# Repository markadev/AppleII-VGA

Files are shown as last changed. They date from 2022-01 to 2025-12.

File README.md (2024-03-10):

# Apple II VGA Card

This project is a VGA card for Apple II computers to ouput a crisp RGB signal to a
VGA monitor instead of having to rely on the composite output. This is accomplished
by snooping the 6502 bus and creating a shadow copy of the video memory within a
Raspberry Pi Pico, then processing the raw video memory contents to output a "perfect"
signal.

    +------+                +-----+      +-----------+
    | 6502 |________________| RAM |______| Composite | 
    | CPU  |  System   \    +-----+      | Video Gen |
    +------+   Bus     |                 +-----------+
                       |    +-----------+
                       \____| Raspberry |_________________\
                            |  Pi Pico  |   640x480 VGA   /
                            +-----------+

These features are currently supported:
 * Generates a 640x480@60 VGA signal with 3 bits per color channel using resistor DACs
 * Text mode (monochrome)
 * Lo-res mode with no color fringing between the chunky pixels
 * Hi-res mode with simulated NTSC artifact color
 * Mixed lo-res and hi-res modes with monochrome text and no color fringing
 * Apple IIe video modes: 80-column text, double-lores, & double-hires
   (thanks to @dkgrizzly and @Paco1979)
 * Soft-monochrome mode to force display as if on a monochrome monitor
 * Some Video-7 RGB card extended graphical modes are implemented
 * Compatibility with Videx VideoTerm modes on Apple II+ (thanks to @abaffa)

I had these goals in mind during design:
 * Generate video out to a more modern display - I don't have any old CRTs for
   displaying composite signals any more and composite to HDMI adapters don't work well.
 * Generate crisp video - I wanted "perfect" video output, the way that it should have
   been barring technical difficulties of displays in 1980. So like, no NTSC artifact
   coloring where it's not supposed to be.
 * Non-invasive - I didn't want to have to solder or modify my logic board.
 * Common parts - The parts to build should be cheap and easy to get anywhere,
   just like the original Apple II
 * Open-source - If this helps anyone else make their Apple II better then that's
   a bonus.

I also wanted to see if a Pi Pico could actually work on an 8-bit CPU bus, since the docs
say it should work but there were no code examples.

## Project Status

This is currently a DIY project that several folks have built on their own, ranging from
[hand-wired prototype boards](docs/prototype_card.jpg) to
[custom](https://user-images.githubusercontent.com/7944844/243266290-d05ce815-0a3d-4464-a4da-49dd44d71e92.jpg)
[PCBs](https://user-images.githubusercontent.com/94628/253134471-0d5ad359-75ae-400a-acfa-885c80c36e78.jpg)
and run in their Apple II+'s and IIe's. I consider it to be pretty stable at this point.

Included in this repo are:
 * The main expansion board [KiCad Project](AppleVGA/), [Schematics](AppleVGA/AppleVGA.pdf),
   [BOM](AppleVGA/AppleVGA_BOM.csv), and [Gerber files](AppleVGA/outputs/)
 * An optional connector board [KiCad Project](AppleVGA-Connector/),
   [Schematics](AppleVGA-Connector/AppleVGA-Connector.pdf),
   [BOM](AppleVGA-Connector/AppleVGA-Connector_BOM.csv),
   and [Gerber files](AppleVGA-Connector/outputs/). (You could also build a custom cable instead)
 * The [source code for the Pi Pico microcontroller](pico/)

If you're going to build a card then check the [assembly guide](docs/Assembly.md) and
[hardware changelog](AppleVGA/CHANGELOG.txt) for important notes.

Many thanks go to the folks in the Discussion area to help push this project forward with bug
fixes & reports, and design ideas!

**Main board**
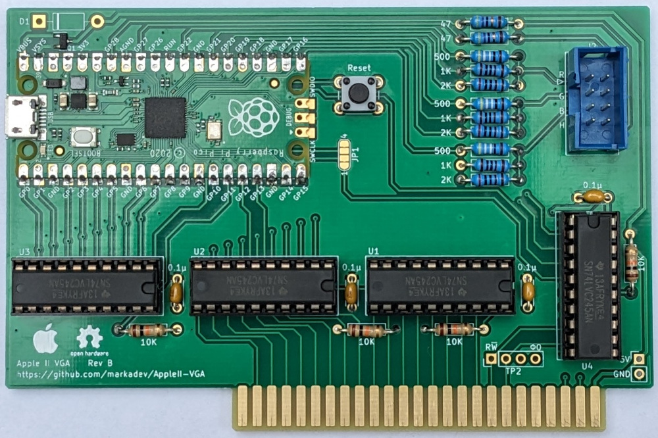
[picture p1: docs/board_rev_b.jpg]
Main board


**Connector board**
_thanks to @swetland for [this idea](https://github.com/markadev/AppleII-VGA/discussions/15#discussioncomment-6432841)_

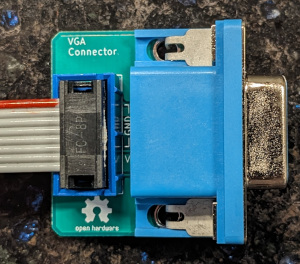
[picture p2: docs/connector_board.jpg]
Connector board


**In the wild**
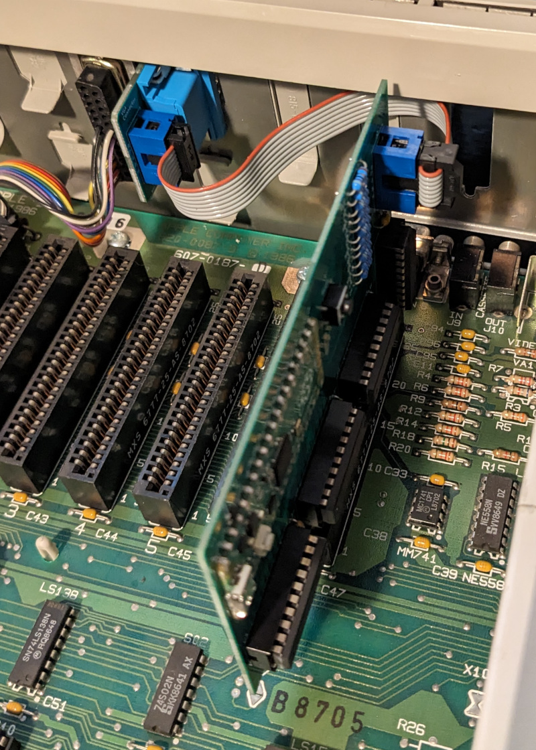
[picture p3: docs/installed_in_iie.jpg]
Live action shot


## Comparisons

Here are a few comparisons of the VGA card output vs composite video through
a cheap composite -> HDMI adapter

**Text**
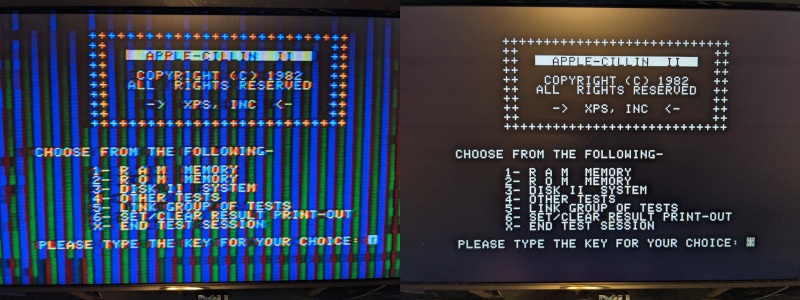
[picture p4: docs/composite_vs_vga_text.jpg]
Text Mode


**Lores**
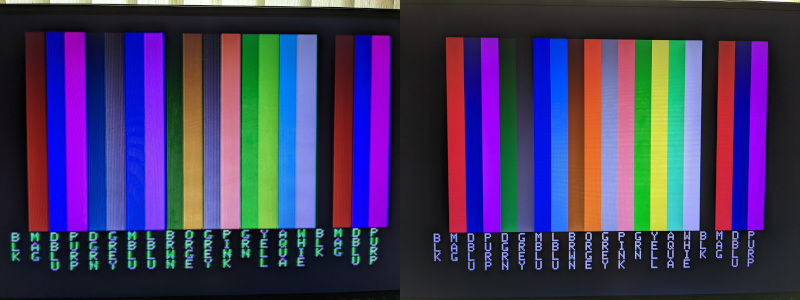
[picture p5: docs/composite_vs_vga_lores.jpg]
Lores Mode


**Hires**
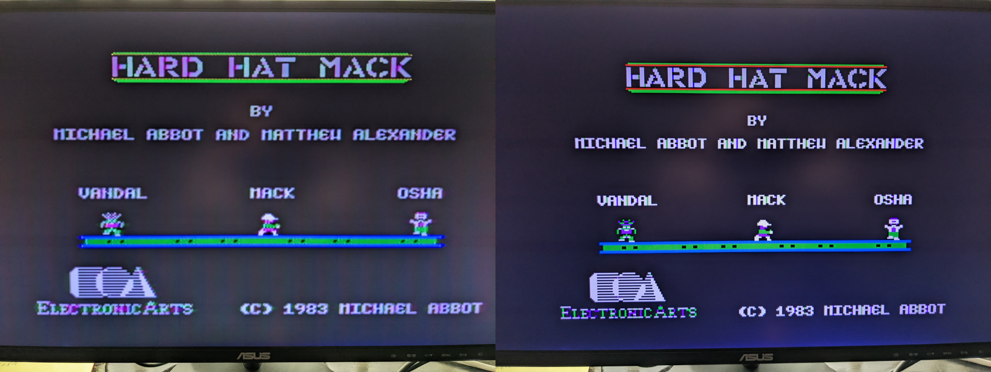
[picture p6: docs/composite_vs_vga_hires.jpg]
Hires Mode


**DHires**
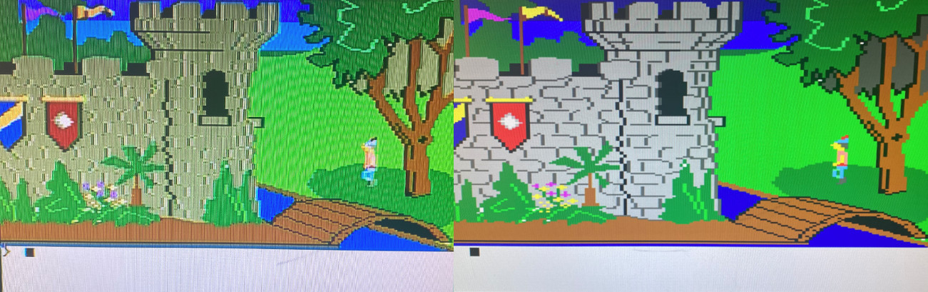
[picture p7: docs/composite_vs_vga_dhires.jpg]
DHires Mode


**80 Columns**
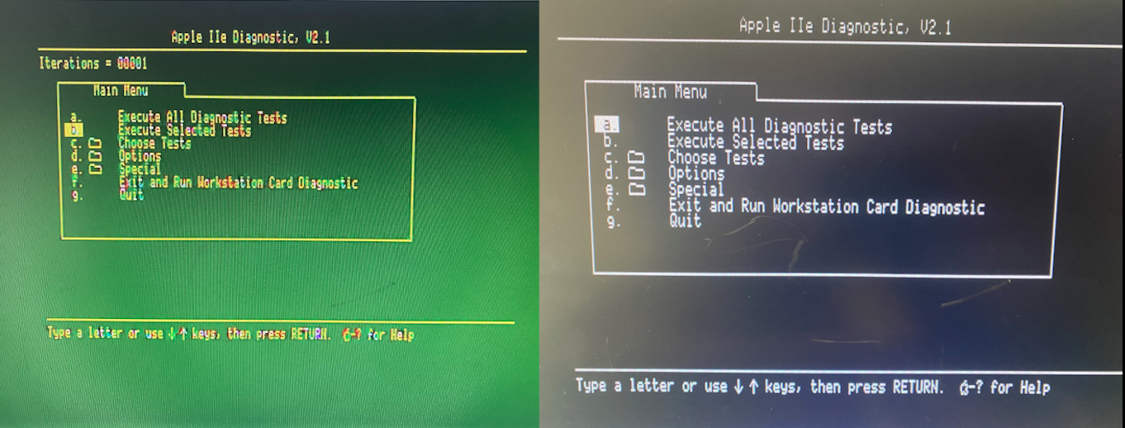
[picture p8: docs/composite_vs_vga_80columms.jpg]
80 Columns Mode


## 80 Column support for the Apple II+

The firmware implements Videx VideoTerm compatibility when there's a VideoTerm card installed
in slot 3. It's not enabled by default but if you have a Videx VideoTerm card in slot 3
then you can enable 80 column VGA support using the Configuration Disk image. The VGA card
can still be installed in any slot.

**Apple II+ running 80 Columns Examples**

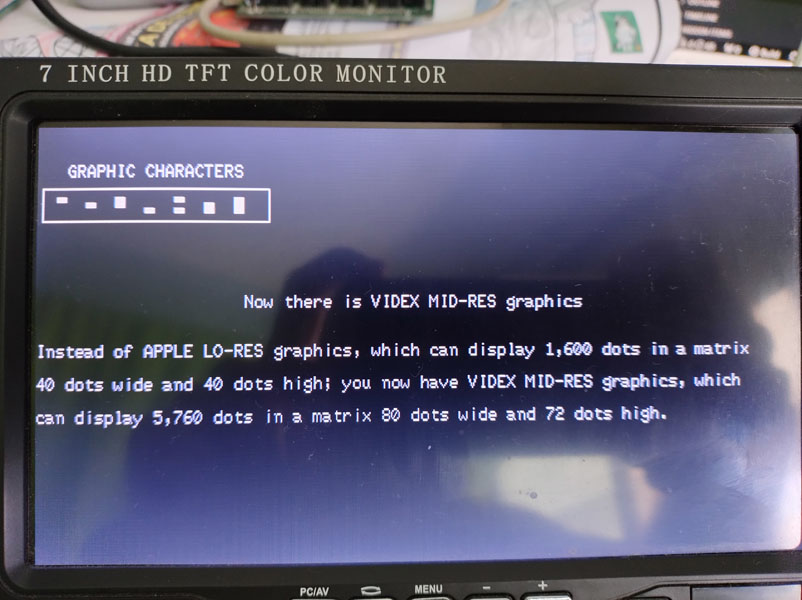
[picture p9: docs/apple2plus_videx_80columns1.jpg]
AppleII 80 Columms Mode 1

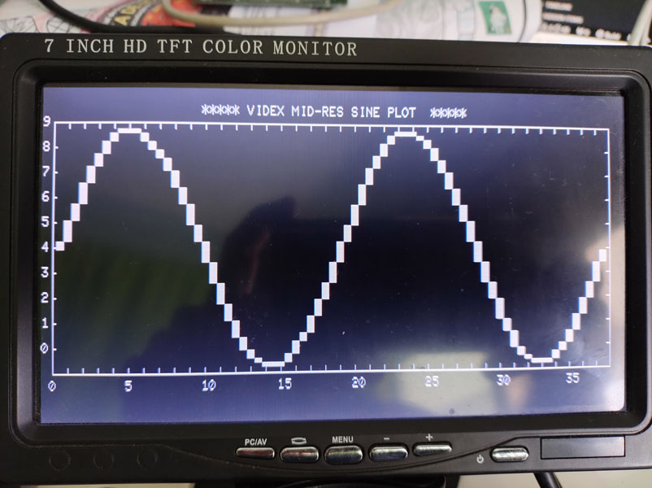
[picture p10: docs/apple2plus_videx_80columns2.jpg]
AppleII 80 Columms Mode 2

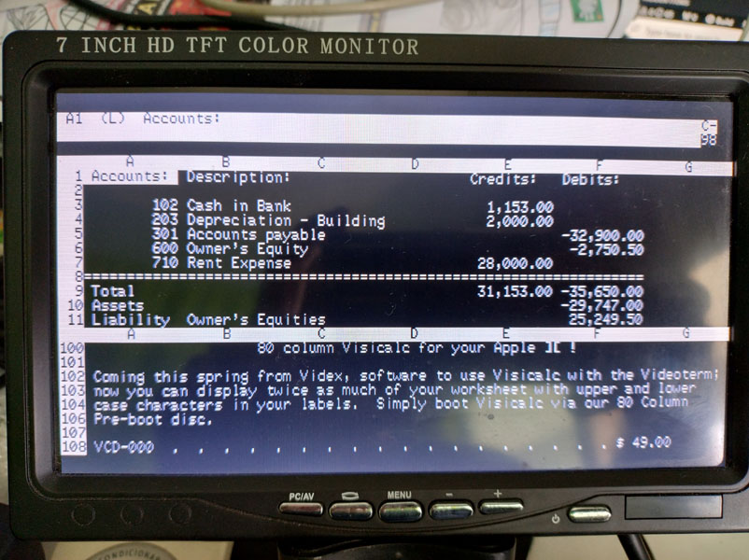
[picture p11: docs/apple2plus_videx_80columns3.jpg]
AppleII 80 Columms Mode 3


## Future work

With the Rev B hardware design, the firmware has access to the Apple bus' SYNC signal
when installed in slot 7. Theoretically the firmware could synchronize the VGA display
scans with the video hardware in the Apple II.

Though possible, it looks like it would be a large overhaul to implement this synchronization
and I've found no real-world use for it so I don't plan on completing this functionality.

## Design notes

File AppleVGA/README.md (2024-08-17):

# AppleII-VGA expansion card

Requirements:
  - KiCad 8.0 or later

This project uses additional KiCad libraries:
 - https://github.com/ncarandini/KiCad-RP-Pico

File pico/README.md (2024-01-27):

# Set Up Raspberry Pi Pico SDK and build the firmware

## Windows Subsystem for Linux (WSL)
Windows Subsystem for Linux (WSL) allows you to install a complete Ubuntu terminal environment in minutes on your Windows machine, allowing you to develop cross-platform applications without leaving Windows. [Install Ubuntu on WSL for Windows](https://ubuntu.com/tutorials/install-ubuntu-on-wsl2-on-windows-10#1-overview)

## Install development packages
```shell
sudo apt update
sudo apt install -y build-essential git cmake gcc-arm-none-eabi
```

## Download the Pico SDK
```shell
git clone https://github.com/raspberrypi/pico-sdk.git ~/pico-sdk
git -C ~/pico-sdk submodule update --init
export PICO_SDK_PATH=~/pico-sdk
```

## Build the firmware for Apple IIe
```shell
git clone https://github.com/markadev/AppleII-VGA.git ~/AppleII-VGA
cd ~/AppleII-VGA/pico
mkdir build
cd build
cmake -DAPPLE_MODEL=IIE -DCMAKE_BUILD_TYPE=Release ..
make
$ ls *uf2
...
applevga.uf2
```

## Build the firmware for Apple II+
```shell
git clone https://github.com/markadev/AppleII-VGA.git ~/AppleII-VGA
cd ~/AppleII-VGA/pico
mkdir build
cd build
cmake -DAPPLE_MODEL=IIPLUS -DCMAKE_BUILD_TYPE=Release ..
make
$ ls *uf2
...
applevga.uf2
```

## Install the firmware
Hold down the BOOTSEL button and connect the Raspberry Pi Pico to your PC via micro USB cable. Once Pico is
connected release the BOOTSEL button. Pi Pico should be connected to PC with USB mass storage device mode.

A disk volume called RPI-RP2 will appear on your computer. Drag and drop the applevga.uf2 file to that volume.
RPI-RP2 will unmount and Pico will start the program.

## Stand-alone test pattern image
There's a test pattern image in the source code that one can set to display immediately at power on, and Pico
microcontroller can be powered entirely from USB. To enable test pattern just uncomment `RENDER_TEST_PATTERN`
flag in `render.h`:
```
// #define RENDER_TEST_PATTERN
```
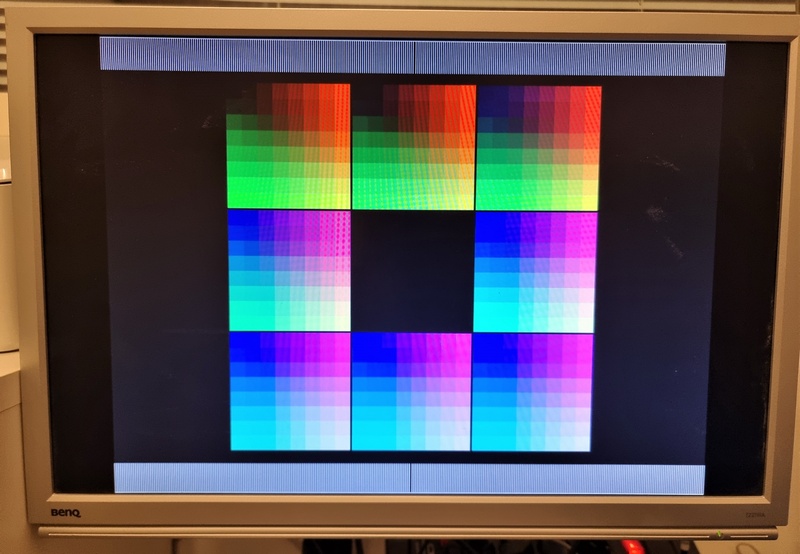
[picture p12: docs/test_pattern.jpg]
Test Pattern


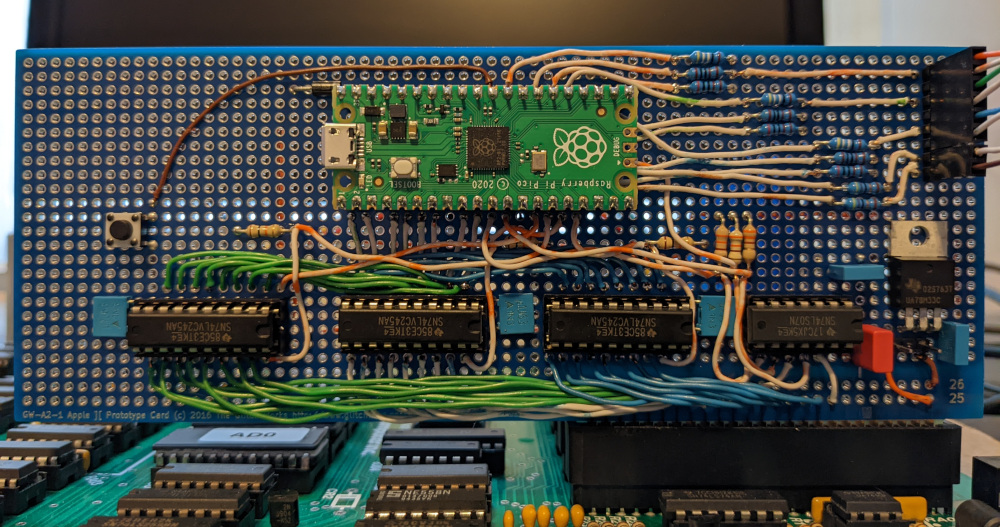
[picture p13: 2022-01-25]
docs/prototype_card.jpg

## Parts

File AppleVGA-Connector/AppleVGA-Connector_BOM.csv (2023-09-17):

# | Reference | Qty | Value | Footprint | DNP | Mfr | MfrNo | MouserNo
1 | J1 | 1 | IDC_02x04 | Connector_IDC:IDC-Header_2x04_P2.54mm_Vertical |  |  |  | 649-75869-232LF
2 | J2 | 1 | DB15HD_Female | AppleVGA-Connector:DSUB-15HD_TE_Connectivity_2311586-4 |  | TE Connectivity | 2311586-4 | 571-2311586-4

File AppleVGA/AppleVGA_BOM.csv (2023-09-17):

# | Reference | Qty | Value | Footprint | DNP | Mfr | MfrNo | MouserNo
1 | C1, C2, C3, C4 | 4 | 0.1μ | Capacitor_THT:C_Disc_D4.3mm_W1.9mm_P5.00mm |  |  |  | 594-A104K15X7RF5TAA
2 | D1 | 1 | 1N5817 | Diode_THT:D_DO-41_SOD81_P10.16mm_Horizontal | DNP | STMicroelectronics | 1N5817 | 511-1N5817
3 | J2 | 1 | VGA | Connector_IDC:IDC-Header_2x04_P2.54mm_Vertical |  |  |  | 649-75869-232LF
4 | Q1 | 1 | DMG2305UX-7 | Package_TO_SOT_SMD:SOT-23 |  | Diodes Incorporated | DMG2305UX-7 | 621-DMG2305UX-7
5 | R1, R2, R3, R15 | 4 | 10K | AppleVGA:R_Axial_DIN0207_L6.3mm_D2.5mm_P10.16mm_Thin_Horizontal |  |  |  | 603-CFR-25JR-5210K
6 | R4, R7, R10 | 3 | 500 | AppleVGA:R_Axial_DIN0207_L6.3mm_D2.5mm_P10.16mm_Thin_Horizontal |  |  |  | 603-MFR-25FBF52-499R
7 | R5, R8, R11 | 3 | 1K | AppleVGA:R_Axial_DIN0207_L6.3mm_D2.5mm_P10.16mm_Thin_Horizontal |  |  |  | 603-MFR-25FBF52-1K
8 | R6, R9, R12 | 3 | 2K | AppleVGA:R_Axial_DIN0207_L6.3mm_D2.5mm_P10.16mm_Thin_Horizontal |  |  |  | 603-MFR-25FBF52-2K
9 | R13, R14 | 2 | 47 | AppleVGA:R_Axial_DIN0207_L6.3mm_D2.5mm_P10.16mm_Thin_Horizontal |  |  |  | 603-MFR-25FTF52-47R
10 | SW1 | 1 | Reset | Button_Switch_THT:SW_PUSH_6mm_H5mm |  | TE Connectivity | FSM4JH | 506-FSM4JH
11 | U1, U2, U3, U4 | 4 | 74LVC245 | Package_DIP:DIP-20_W7.62mm_Socket |  | TI | SN74LVC245AN | 595-SN74LVC245AN
12 | U6 | 1 | Pico | MCU_RaspberryPi_and_Boards:RPi_Pico_SMD_TH

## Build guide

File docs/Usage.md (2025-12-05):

# Using the VGA card

After you load on the firmware for your respective Apple II system (II+ or IIe)
the VGA card is generally plug-and-play. Plug it in, power on your Apple II
and that's it.

There are some optional features and other controls that can be changed using the
menu-based Configuration disk or by directly using `POKE` commands.

## Soft Monochrome Mode

Due to the way hires mode works to generate color, some software looks best on a monochrome
monitor where close pixels won't blend together into a colored mess. A software-controlled
monochrome mode can be enabled to disable the hires mode artifact color simulation.

This can be changed by writing to bit 7 of soft-switch at address `$c021`. From Applesoft Basic:

    REM ENABLE SOFT MONOCHROME
    POKE 49185, 128

    REM DISABLE SOFT MONOCHROME
    POKE 49185, 0

When enabled this will:
 * Change all modes to render as if it was connected to a high resolution monochrome monitor.
   "Colors" originally created by NTSC artifacting will appear as sequences of dots.
 * Switch to the monochrome color palette (black & white by default)

This setting will be saved across power-cycles if the "Save" command is executed.

## Hires mode smoothing

By default the VGA card will output hard pixel transitions in hires and double hires modes that is more
consistent with how an RGB card of the era would look. However, some software is designed to work best
on composite video monitors that will have smooth artifact coloring instead of discrete RGB pixels.

In this case the VGA card can emulate smoother NTSC video processing for the hires and double hires
video modes.

This can be changed by writing to bit 7 of soft-switch at address `$c02a`. From Applesoft Basic:

    REM ENABLE SMOOTH HIRES
    POKE 49194, 128

    REM DISABLE SMOOTH HIRES
    POKE 49194, 0

When enabled:
 * hires mode will have softer edges on pixel transitions across a scanline and softer color transitions
   resulting in more artifact color bleed
 * double-hires mode will switch from rendering discrete RGB pixels to filtering the video signal through
   the same filter as hires mode, resulting in softer edges between color changes and more accurate rendering
   of software that originally required the use of a composite monitor

This setting will be saved across power-cycles if the "Save" command is executed.

## Device Registers

The card's device registers can be written to change some settings. These settings persist across
CPU resets and will be saved permanently if the "Save" command is executed (see register 4).

The register base address depends on the slot number in which you installed the card:

    $c080 + $10*n

Or in Applesoft Basic:

    SLOT=4
    BASEADDR=49280+16*SLOT

The various register offsets can then be written to:

    POKE BASEADDR, <value>
    POKE BASEADDR+1, <value>
    POKE BASEADDR+2, <value>
    ...

### Register 0 - Feature Select

**[write-only]**
This register controls enablement of some features of the card

| bit(s) | Description
| --- | ---
|  7:4 | reserved
| 3 | Setting to 1 will disable Videx VideoTerm support (II+ only)
| 2 | Setting to 1 will enable Videx VideoTerm support (II+ only)
| 1 | Setting to 1 will disable simulated scanline rendering
| 0 | Setting to 1 will enable simulated scanline rendering

### Register 1 - Monochrome color selection

**[write-only]**
This register controls the output color when soft-monochrome mode is enabled

| bit(s) | Description
| --- | ---
| 7 | Setting to 1 will disable forcing the use of the monochrome color in text modes.
| 6 | Setting to 1 will force the use of the chosen monochrome color in text modes, even when soft-monochrome mode is not enabled.
|  5:4 | Setting non-zero will choose a background color (1=black, 2=green, 3=amber)
|  3:2 | reserved
|  1:0 | Setting non-zero will choose a foreground color (1=white, 2=green, 3=amber)

### Registers 2 & 3 - Text character pattern offset & data

**[write-only]**
These registers allow the character patterns used by the text mode character generator
to be modified. To update the patterns of one or more chacters you would first write the
character number of the character to update to register 2, and then write 8 bytes of the
character's bit pattern to register 3. To update multiple contiguous characters you can
just continue writing 8 bytes per character to update.

For example, to replace the '#' character (character number `$A3`) with '£':

    POKE BASEADDR+2, 163
    POKE BASEADDR+3, 184
    POKE BASEADDR+3, 196
    POKE BASEADDR+3, 132
    POKE BASEADDR+3, 142
    POKE BASEADDR+3, 132
    POKE BASEADDR+3, 132
    POKE BASEADDR+3, 250
    POKE BASEADDR+3, 128

Changes made to the text character patterns will be saved permanently when the "Save" command
is executed.

### Register 4 - Device command

**[write-only]**
This register allows a one-shot device command to be executed. The value written is the command
to execute.

| value | Description
| --- | ---
| $00 | Load the default configuration values
| $01 | Load the stored configuration from flash. This automatically happens on power-up.
| $02 | Save the current configuration to flash
| $10 - $1f | Load one of the built-in character ROMs

#### Saving settings permanently

To permanently save changes to flash, like say you update a text character pattern or want to always
have scanline emulation enabled, then you just execute command `$02`:

    POKE BASEADDR+4, 2

To permanently restore the default settings (text font, monochrome colors, etc) you would need to execute
command `$00` to revert the RAM settings to the defaults and then `$02` to save the change to flash:

    POKE BASEADDR+4, 0
    POKE BASEADDR+4, 2

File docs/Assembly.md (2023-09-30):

# Notes on building a VGA card

Before building a card you will need to make a decision on how you want the VGA connector to be mounted:

1. You could build a connector board, which works well for an Apple IIe but will block a IIe slot where it's mounted.
2. You could build a custom cable from the pin header to a shrouded DB-15HD connector that comes out the back.
   This could work for both Apple II+ and Apple IIe's.
3. You could build something else! Maybe you want to pipe the output directly into a VGA -> HDMI converter?

In the parts lists I included specific part numbers when it matters and also included the exact
[Mouser](https://www.mouser.com/) part numbers for all the parts I used. You do not need to buy from Mouser but you
can use their part database as a reference to find compatible parts from your supplier.

You should also check the schematics for any special part notes that I might have missed here.

## Getting parts

### Main board

Check the [BOM](../AppleVGA/AppleVGA_BOM.csv) for the main board. Important notes about parts (also check the
schematic for notes):

 * The DAC resistors R4-R12 should ideally be 1% tolerance but it's not a strict requirement
 * Only one of D1 or Q1 need to be installed so you only need to buy one of them (_they are both inexpensive
   parts so you could buy both and decide later!_)
   * If you want to avoid tiny surface mount parts then choose D1
   * If you can't find one of them in stock then pick the one you can find in stock
   * Otherwise prefer to install Q1
 * I recommend also getting 4 [20-pin DIP IC sockets](https://www.mouser.com/ProductDetail/571-1-2199298-6) for the ICs
 * It's your choice whether to surface mount the Pico or to use an additional set of 1x20 pin headers. Both will work
   without obstructing access to the Pico's USB port for firmware updates.
 * You can use the less expensive break-apart 2x4 pin headers for J2
 * The 'Reset' button is optional and mainly just helps me during firmware development.

### VGA connector board

Check the [BOM](../AppleVGA-Connector/AppleVGA-Connector_BOM.csv) for the connector board. If you need to
substitute the DB-15HD connector then double-check that the footprint of the replacement part is the same as
the original. The datasheet for the original part will be linked from Mouser's part page.

You will also need a ribbon cable to connect to the main board which can be made with:
 * 2 * [2x4 wire housings](https://www.mouser.com/ProductDetail/710-61200823021)
 * about 6 inches of 8 conductor ribbon cable

And if you want to mount the connector to the back of a IIe then you'll also want to get some hex standoffs to
screw into the VGA connector. Sorry I don't have a source for this, just a drawer of 'em that I've collected
over the years. The manufacturer of the connector you buy should have a corresponding part.

### VGA connector cable

If you want to build a custom cable instead of the connector board then it can be done with a few parts
and using the [connector board schematic](../AppleVGA-Connector/AppleVGA-Connector.pdf) as a wiring guide.

Parts:
 * A "Dupont" wire crimper kit [something like this](https://www.amazon.com/gp/product/B07VQ6YNSC)
 * Either 2 1x4 housings or 1 2x4 housing
 * A DB15-HD female connector (solder-bucket connection is easiest to use)
 * A DB-9 shroud [like this](https://www.mouser.com/ProductDetail/601-40-9709H)
 * A bit of 8 conductor cable, as long as you need. Scrap ethernet cable works OK.

## Getting a PCB

You can use the gerber files for the boards to get a PCB made at any PCB manufacturer you'd like. You usually
just zip up the whole directory and upload it to their site for processing. Take care to understand the
manufacturer's requirements for the edge connector though even the cheap PCB makers have automated design checks
to validate the PCB is compatible.

 * Gerber files for the main PCB: [here](../AppleVGA/outputs)
 * Gerber files for the connector PCB: [here](../AppleVGA-Connector/outputs)

For my board I used JLCPCB with excellent results. The gold-plated edge connector came out great and it was
not too expensive. I changed a few settings from their default settings:

 * PCB thickness: 1.2mm
 * Surface Finish: ENIG
 * Remove Order Number: Specify a location
 * Gold Fingers: yes
 * 30° finger chamfered: yes

You could exclude the gold plating and higher quality surface finish to reduce the cost. A standard PCB thickness
is 1.6mm but I found 1.6mm cards to be hard to get into my IIe's expansion slots and flexed my mainboard a lot during
insertion so I reduced to 1.2mm and have not had any issues.

## Assembling the board

You can assemble the board using a general assembly guideline of installing the lowest profile components first:

1. the Q1 surface-mount MOSFET (if using the MOSFET)
2. resistors
3. low-profile inline capacitors (if you have them)
4. the D1 diode (if not using the MOSFET)
5. IC sockets
6. Reset button (optional)
7. tall capacitors (if you have them)
8. Pico pin headers
9. VGA IDC connector or pin header. Ensure that pin 1 of the connector housing is aligned with pin 1 on the PCB
   so that the polarity notch is facing inward.

If you're surface mounting the Pico then it can be done last.

Main board image

If you're building a connector board too then just solder it up, ensuring the IDC connector is oriented correctly.

Connector board image

## Installing the Pico firmware

To install firmware on the Pico you'll need a USB to micro-USB cable.

1. Download a firmware file for your Apple model (II+ or IIe)
   [from the release page](https://github.com/markadev/AppleII-VGA/releases)
2. Hold the Pico's button down while connecting the Pico's USB to a PC
3. Your OS will detect a virtual USB-attached disk
4. Drag and drop the (`.uf2`) firmware file onto the virtual USB drive 
5. The Pico will install the firmware and then reboot

## Power-up test

To perform a simple test of the VGA output circuitry:

1. Remove the board from any Apple II
2. Connect the VGA monitor
3. Connect the Pico's USB to a PC or USB charger
4. The board should be outputting an Apple II text screen full of inverse `@` characters

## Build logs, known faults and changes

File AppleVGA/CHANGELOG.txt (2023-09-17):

Hardware Changelog

# Rev B - Sept 9, 2023

Updated design suitable for PCB manufacturing and hand-soldering

Non-functional changes:
 * The 74LS07 and related pull-up resistors have been replaced with another 74LVC245
   to reduce unique part count and waste less power
 * The dedicated 3.3v regulator has been removed in favor of using the voltage
   regulator on the Pico
 * MOSFET Q1 may be used instead of diode D1 in the Pico's power supply which
   will reduce wasted power

Functional/breaking changes:
 * The VGA connector J2 was changed from a 1x8 pin header to a 2x4 pin header/IDC connector
 * Pico GPIO10 is now connected to the Apple bus SYNC signal (via U4 for voltage translation).
   There is jumper block JP1 with cuttable & bridgeable pads for reconfiguring GPIO10 back
   to the Rev A behavior (U3 direction control) (Big thanks to Brian @swetland for this idea)

**Do not use older firmware on this board revision**. If you are reusing a Pico from a build
of the rev A circuit then make sure to install the latest firmware first. The latest firmware
will work with both rev A and rev B circuit designs.

# Rev A - Jan 2, 2022

Initial design for laying out and wiring chips on a protoboard

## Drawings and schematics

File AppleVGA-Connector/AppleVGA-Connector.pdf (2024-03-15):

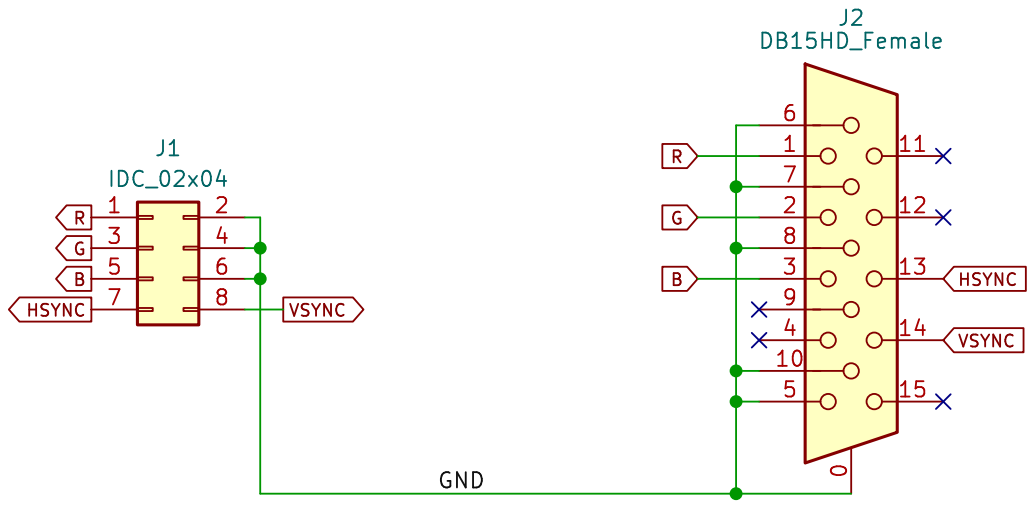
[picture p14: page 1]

Id: 1/1 Title: Apple II VGA Connector Board

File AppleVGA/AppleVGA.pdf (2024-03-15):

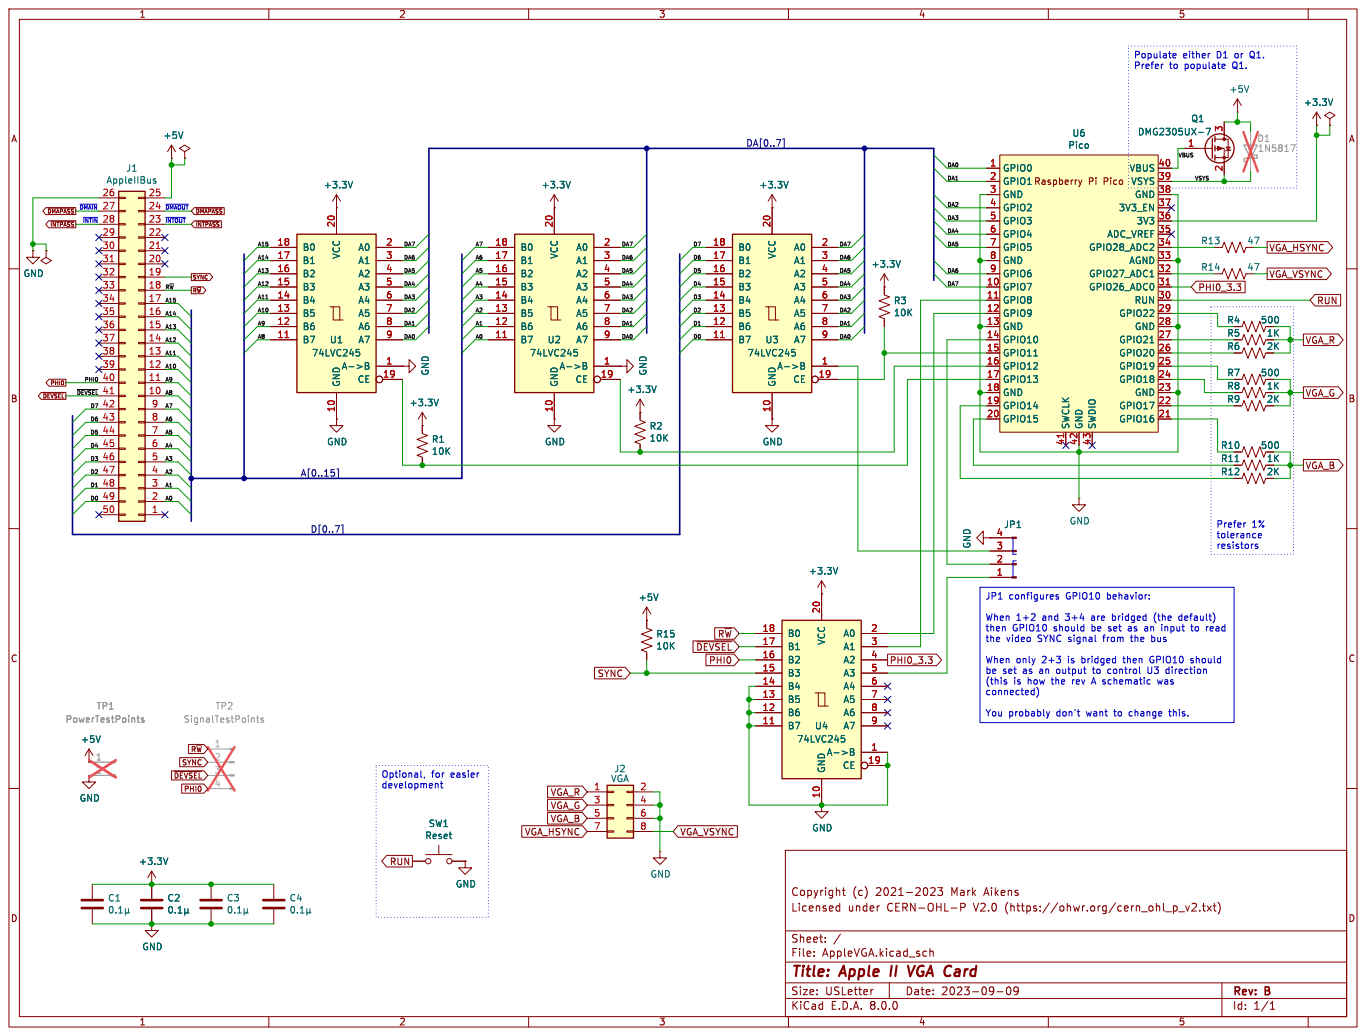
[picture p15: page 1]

2 3 +3.3V U6 Pico GPIO0 1 GPIO7 10 GPIO8 11 GPIO9 12 GND 13 GPIO10 14 GPIO11 15 GPIO12 16 GPIO13 17 GND 18 GPIO14 19 GPIO1 2 GPIO15 20 GPIO16 21 GPIO17 22 GND 23 GPIO18 24 GPIO19 25 GPIO20 26 GPIO21 27 GND 28 GPIO22 29 GND 3 RUN 30 GPIO26_ADC0 31 GPIO27_ADC1 32 AGND 33 GPIO28_ADC2 34 ADC_VREF 35

then GPIO10 should be set as an input to read
the video SYNC signal from the bus When only 2+3 is bridged then GPIO10 should

Id: 1/1 Title: Apple II VGA Card

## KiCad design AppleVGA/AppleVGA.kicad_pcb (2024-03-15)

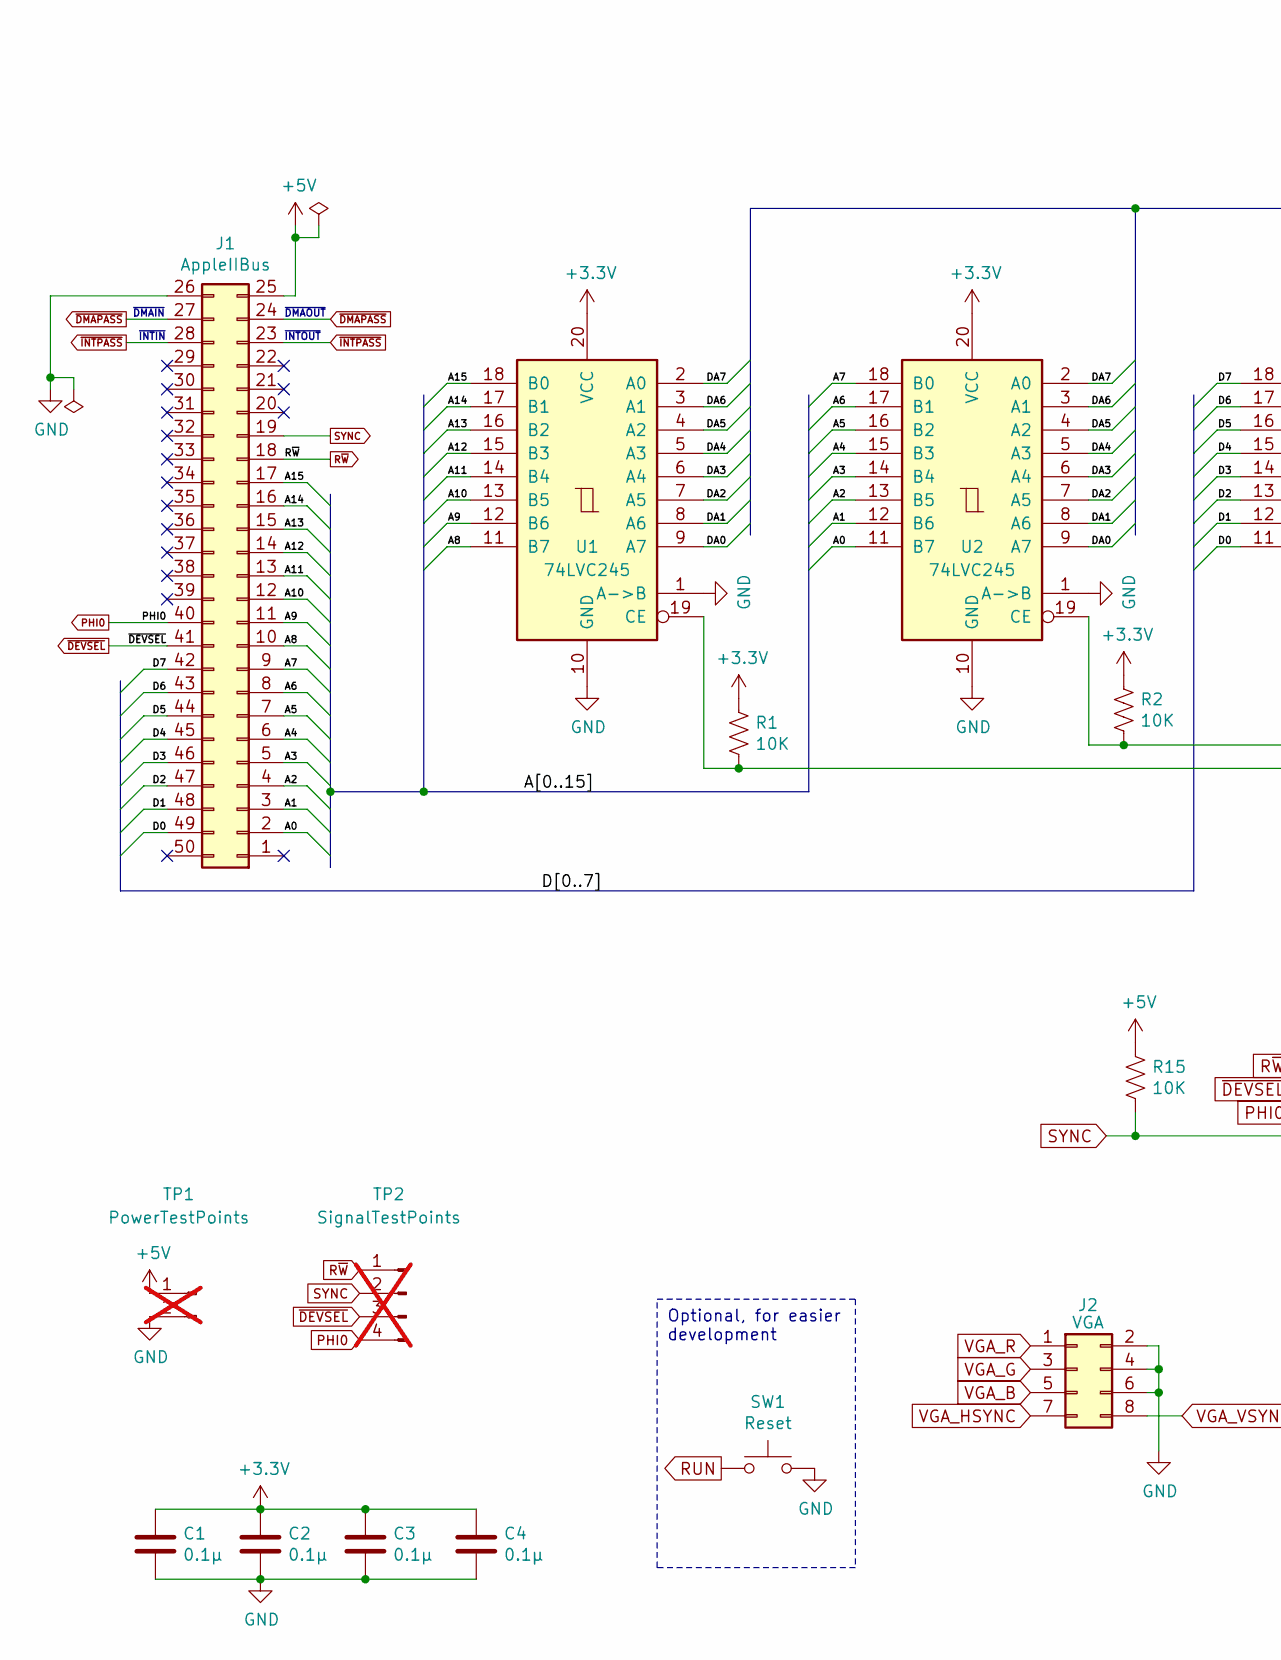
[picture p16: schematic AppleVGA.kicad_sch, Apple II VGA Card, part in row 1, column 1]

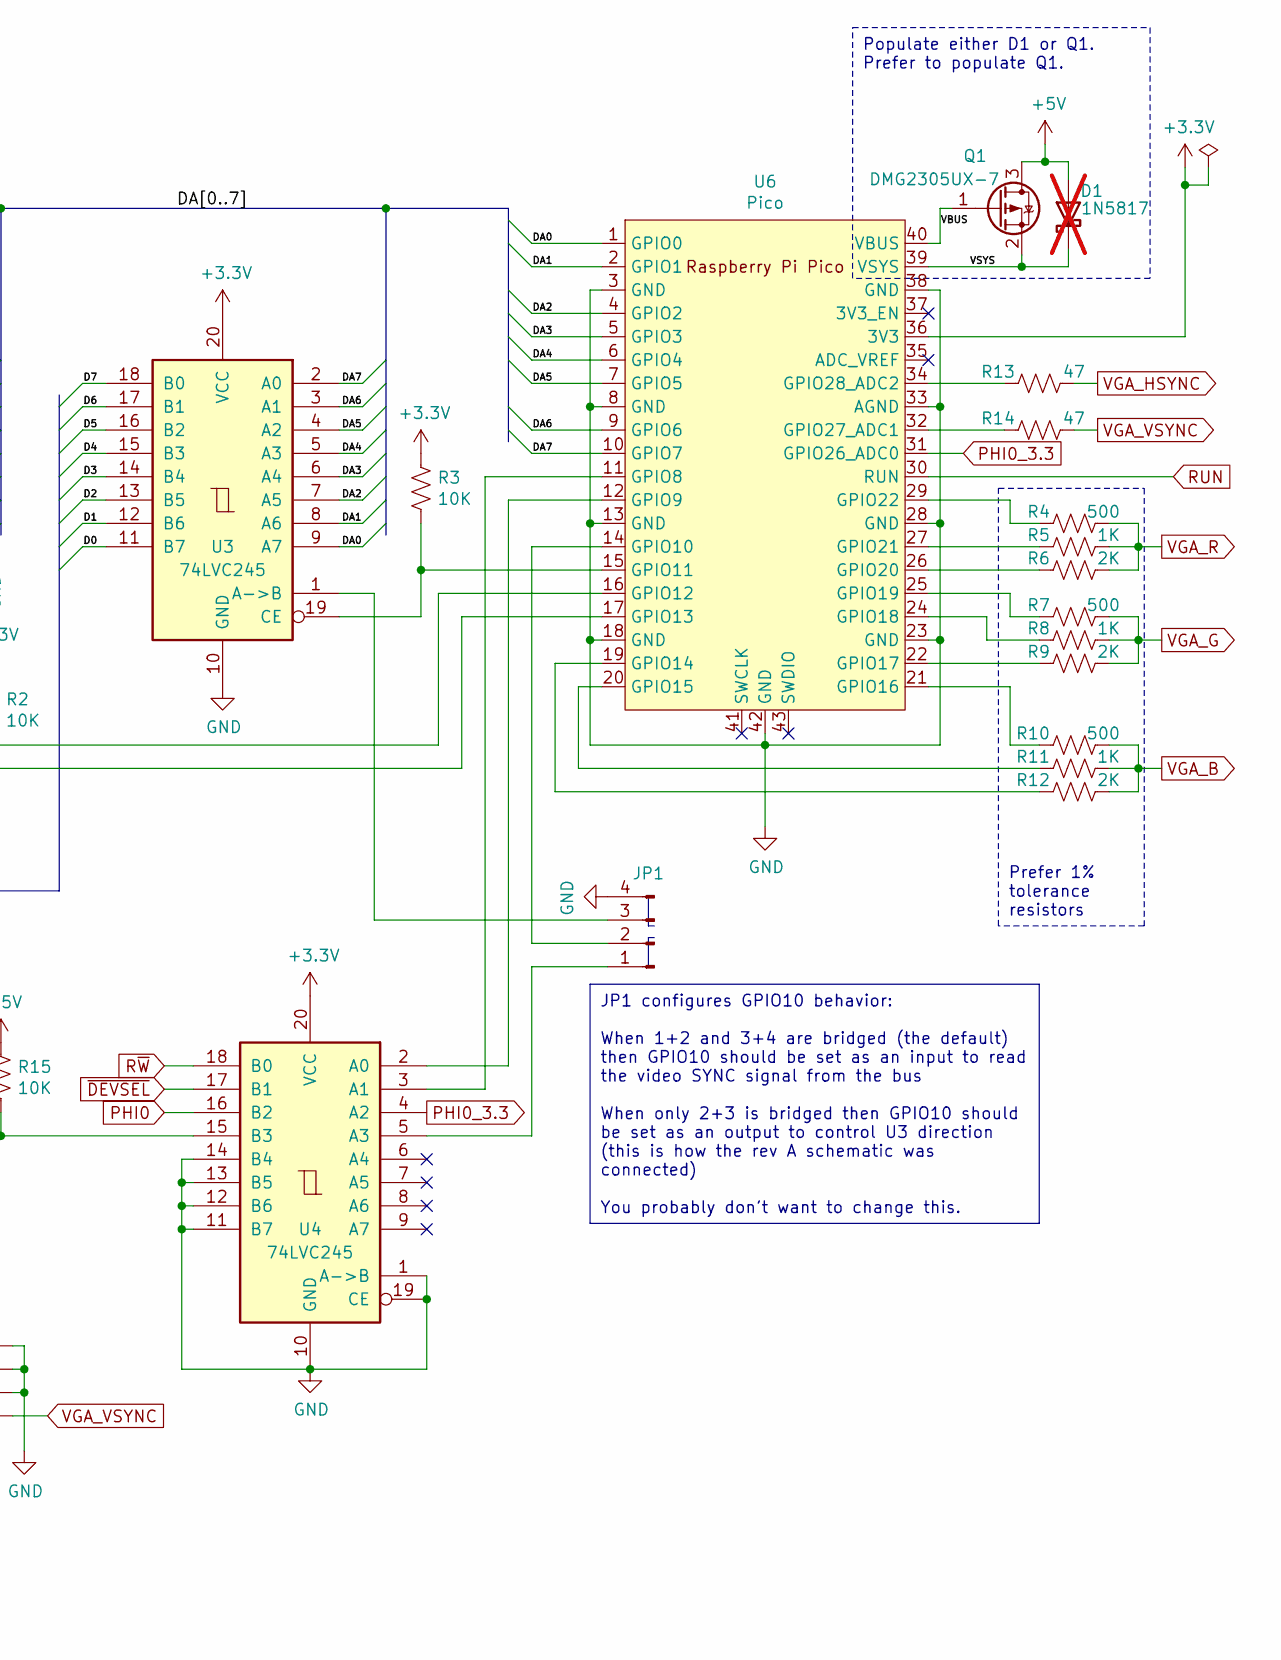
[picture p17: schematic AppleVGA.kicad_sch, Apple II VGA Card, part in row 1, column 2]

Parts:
C1, C2, C3, C4: 0.1μ; C_Disc_D4.3mm_W1.9mm_P5.00mm; MouserNo 594-A104K15X7RF5TAA
D1: 1N5817; D_DO-41_SOD81_P10.16mm_Horizontal; MouserNo 511-1N5817; not fitted
J1: AppleIIBus; AppleIIBus_Edge
J2: VGA; IDC-Header_2x04_P2.54mm_Vertical; MouserNo 649-75869-232LF
JP1: JumperPads; SolderJumper-4_P1.3mm_Bridged12_34_RoundedPad1.0x1.5mm_Numb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
Q1: DMG2305UX-7; SOT-23; MouserNo 621-DMG2305UX-7
R1, R2, R3, R15: 10K; R_Axial_DIN0207_L6.3mm_D2.5mm_P10.16mm_Thin_Horizontal; MouserNo 603-CFR-25JR-5210K
R4, R7, R10: 500; R_Axial_DIN0207_L6.3mm_D2.5mm_P10.16mm_Thin_Horizontal; MouserNo 603-MFR-25FBF52-499R
R5, R8, R11: 1K; R_Axial_DIN0207_L6.3mm_D2.5mm_P10.16mm_Thin_Horizontal; MouserNo 603-MFR-25FBF52-1K
R6, R9, R12: 2K; R_Axial_DIN0207_L6.3mm_D2.5mm_P10.16mm_Thin_Horizontal; MouserNo 603-MFR-25FBF52-2K
R13, R14: 47; R_Axial_DIN0207_L6.3mm_D2.5mm_P10.16mm_Thin_Horizontal; MouserNo 603-MFR-25FTF52-47R
SW1: Reset; SW_PUSH_6mm_H5mm; MouserNo 506-FSM4JH
TP1: PowerTestPoints; PinHeader_1x02_P2.54mm_Vertical; not fitted
TP2: SignalTestPoints; PinHeader_1x04_P2.54mm_Vertical; not fitted
U1, U2, U3, U4: 74LVC245; DIP-20_W7.62mm_Socket; MouserNo 595-SN74LVC245AN
U6: Pico; RPi_Pico_SMD_TH

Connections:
+3.3V: C1.1, C2.1, C3.1, C4.1, R1.1, R2.1, R3.1, U1.20 (VCC), U2.20 (VCC), U3.20 (VCC), U4.20 (VCC), U6.36 (3V3)
+5V: D1.2 (A), J1.25, Q1.3 (D), R15.1, TP1.1
/A0: J1.2, U2.11 (B7)
/A1: J1.3, U2.12 (B6)
/A2: J1.4, U2.13 (B5)
/A3: J1.5, U2.14 (B4)
/A4: J1.6, U2.15 (B3)
/A5: J1.7, U2.16 (B2)
/A6: J1.8, U2.17 (B1)
/A7: J1.9, U2.18 (B0)
/A8: J1.10, U1.11 (B7)
/A9: J1.11, U1.12 (B6)
/A10: J1.12, U1.13 (B5)
/A11: J1.13, U1.14 (B4)
/A12: J1.14, U1.15 (B3)
/A13: J1.15, U1.16 (B2)
/A14: J1.16, U1.17 (B1)
/A15: J1.17, U1.18 (B0)
/D0: J1.49, U3.11 (B7)
/D1: J1.48, U3.12 (B6)
/D2: J1.47, U3.13 (B5)
/D3: J1.46, U3.14 (B4)
/D4: J1.45, U3.15 (B3)
/D5: J1.44, U3.16 (B2)
/D6: J1.43, U3.17 (B1)
/D7: J1.42, U3.18 (B0)
/DA0: U1.9 (A7), U2.9 (A7), U3.9 (A7), U6.1 (GPIO0)
/DA1: U1.8 (A6), U2.8 (A6), U3.8 (A6), U6.2 (GPIO1)
/DA2: U1.7 (A5), U2.7 (A5), U3.7 (A5), U6.4 (GPIO2)
/DA3: U1.6 (A4), U2.6 (A4), U3.6 (A4), U6.5 (GPIO3)
/DA4: U1.5 (A3), U2.5 (A3), U3.5 (A3), U6.6 (GPIO4)
/DA5: U1.4 (A2), U2.4 (A2), U3.4 (A2), U6.7 (GPIO5)
/DA6: U1.3 (A1), U2.3 (A1), U3.3 (A1), U6.9 (GPIO6)
/DA7: U1.2 (A0), U2.2 (A0), U3.2 (A0), U6.10 (GPIO7)
/VBUS: Q1.1 (G), U6.40 (VBUS)
/VSYS: D1.1 (K), Q1.2 (S), U6.39 (VSYS)
GND: C1.2, C2.2, C3.2, C4.2, J1.26, J2.2, J2.4, J2.6, JP1.4, SW1.2, TP1.2, U1.1 (A->B), U1.10 (GND), U2.1 (A->B), U2.10 (GND), U3.10 (GND), U4.1 (A->B), U4.10 (GND), U4.11 (B7), U4.12 (B6), U4.13 (B5), U4.14 (B4), U4.19 (CE), U6.3 (GND), U6.8 (GND), U6.13 (GND), U6.18 (GND), U6.23 (GND), U6.28 (GND), U6.33 (AGND), U6.38 (GND), U6.42 (GND)
unnamed: JP1.1, U4.5 (A3)
unnamed: JP1.2, U6.14 (GPIO10)
unnamed: JP1.3, U3.1 (A->B)
unnamed: R1.2, U1.19 (CE), U6.17 (GPIO13)
unnamed: R2.2, U2.19 (CE), U6.16 (GPIO12)
unnamed: R3.2, U3.19 (CE), U6.15 (GPIO11)
unnamed: U4.2 (A0), U6.12 (GPIO9)
unnamed: U4.3 (A1), U6.11 (GPIO8)
unnamed: R12.1, U6.19 (GPIO14)
unnamed: R11.1, U6.20 (GPIO15)
unnamed: R10.1, U6.21 (GPIO16)
unnamed: R9.1, U6.22 (GPIO17)
unnamed: R8.1, U6.24 (GPIO18)
unnamed: R7.1, U6.25 (GPIO19)
unnamed: R6.1, U6.26 (GPIO20)
unnamed: R5.1, U6.27 (GPIO21)
unnamed: R4.1, U6.29 (GPIO22)
unnamed: R14.1, U6.32 (GPIO27_ADC1)
unnamed: R13.1, U6.34 (GPIO28_ADC2)
PHI0: J1.40, TP2.4, U4.16 (B2)
PHI0_3.3: U4.4 (A2), U6.31 (GPIO26_ADC0)
RUN: SW1.1, U6.30 (RUN)
R~W: J1.18, TP2.1, U4.18 (B0)
SYNC: J1.19, R15.2, TP2.2, U4.15 (B3)
VGA_B: J2.5, R10.2, R11.2, R12.2
VGA_G: J2.3, R7.2, R8.2, R9.2
VGA_HSYNC: J2.7, R13.2
VGA_R: J2.1, R4.2, R5.2, R6.2
VGA_VSYNC: J2.8, R14.2
~DEVSEL: J1.41, TP2.3, U4.17 (B1)
~DMAPASS: J1.24, J1.27
~INTPASS: J1.23, J1.28

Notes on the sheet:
Optional, for easier development
Populate either D1 or Q1. Prefer to populate Q1.
JP1 configures GPIO10 behavior: When 1+2 and 3+4 are bridged (the default) then GPIO10 should be set as an input to read the video SYNC signal from the bus When only 2+3 is bridged then GPIO10 should be set as an output to control U3 direction (this is how the rev A schematic was connected) You pro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
Prefer 1% tolerance resistors
~{DMAIN}
~{INTOUT}
~{DMAOUT}
~{INTIN}

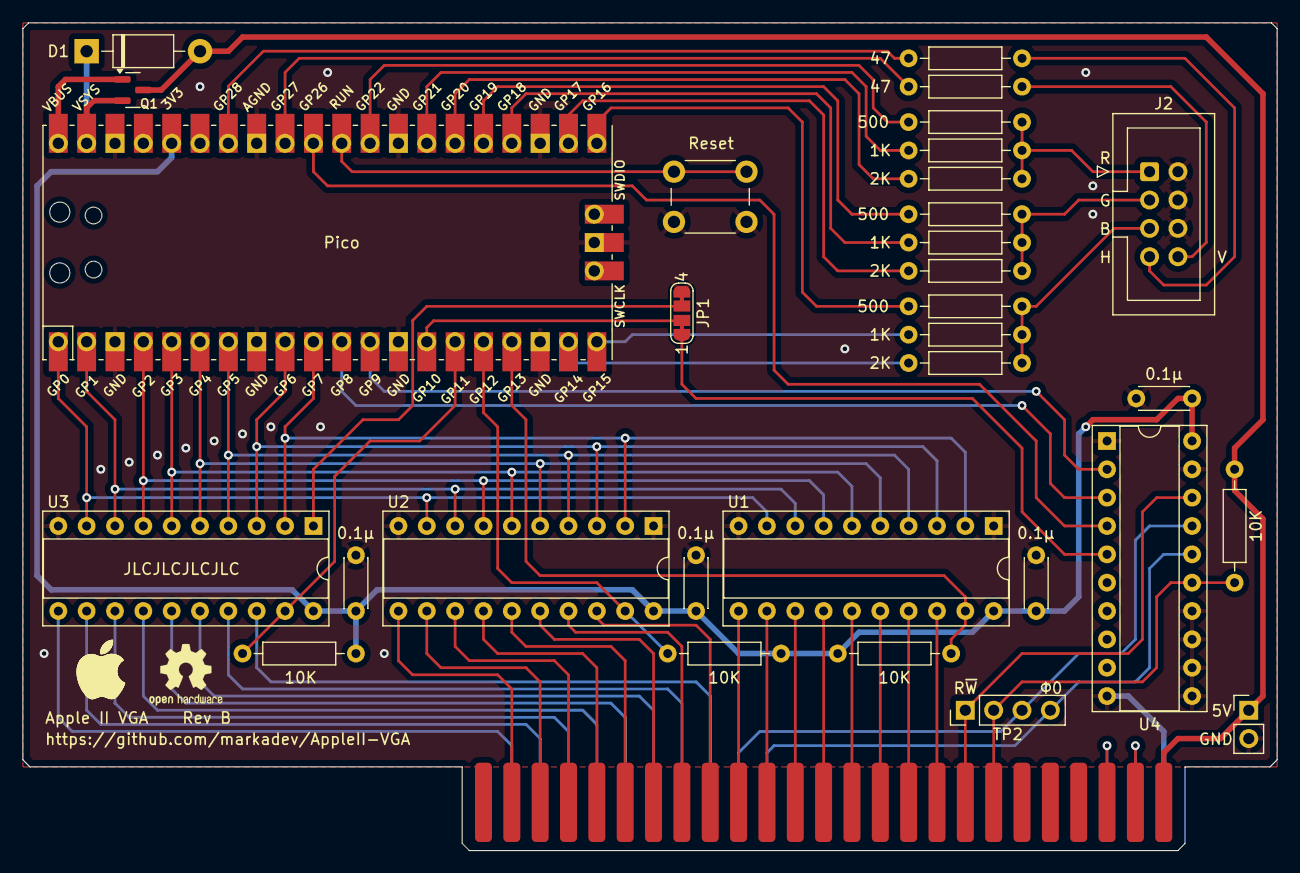
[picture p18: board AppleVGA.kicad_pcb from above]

Board: 2 copper layers, 112.4 x 74.2 mm, 33 parts (0 on the bottom side), 69 nets.

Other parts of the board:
LOGO1: AppleLogo_5mm

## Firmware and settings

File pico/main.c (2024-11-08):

#include <pico/stdlib.h>
#include <pico/multicore.h>
#include <hardware/clocks.h>
#include "abus.h"
#include "board_config.h"
#include "config.h"
#include "render.h"
#include "vga.h"


static void core1_main() {
    vga_init();
    render_init();
    render_loop();
}

int main() {
    // Adjust system clock for better dividing into other clocks
    set_sys_clock_khz(CONFIG_SYSCLOCK * 1000, true);

    // Setup the on-board LED for debugging
    gpio_init(PICO_DEFAULT_LED_PIN);
    gpio_set_dir(PICO_DEFAULT_LED_PIN, GPIO_OUT);

    config_load();

    multicore_launch_core1(core1_main);

    abus_init();
    abus_loop();
}

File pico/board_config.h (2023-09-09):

#pragma once

#define CONFIG_SYSCLOCK 126.0 /* MHz */

// Pin configuration
#define CONFIG_PIN_APPLEBUS_DATA_BASE 0 /* 8+2 pins */
#define CONFIG_PIN_APPLEBUS_DEVSEL (CONFIG_PIN_APPLEBUS_DATA_BASE + 8)
#define CONFIG_PIN_APPLEBUS_RW (CONFIG_PIN_APPLEBUS_DATA_BASE + 9)
#define CONFIG_PIN_APPLEBUS_SYNC 10
#define CONFIG_PIN_APPLEBUS_CONTROL_BASE 11 /* 3 pins */
#define CONFIG_PIN_APPLEBUS_PHI0 26
#define CONFIG_PIN_HSYNC 28
#define CONFIG_PIN_VSYNC 27
#define CONFIG_PIN_RGB_BASE 14 /* 9 pins */

// Other resources
#define CONFIG_VGA_PIO pio0
#define CONFIG_VGA_SPINLOCK_ID 31
#define CONFIG_ABUS_PIO pio1

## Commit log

2021-11-10 Initial commit of pico source skeleton
2021-11-14 Fix horizontal pixel jitter
    Use DMA to write the test scanlines to avoid FIFO underruns
    and adjust the timings to remove jitter caused by the
    fractional clock dividers.
    [vga.c]
2021-11-14 Cleanup: move the VGA DMA setup into vga.c
2021-11-14 Add cheap pixel doubling/tripling/quadrupling and allow the next scanline to be built while the current one is being DMA'd
2021-11-17 use 32-bit DMA transfers for VGA pixel data
2021-11-27 Shorten the hsync signal length
    This allows dummy scanlines in the vertical blanking
    period to be much shorter.
    [vga.c]
2021-11-27 Clean up VGA frame setup
2021-12-25 Fix mapping of text line to memory address in textmode
    [main.c]
2021-12-27 Fix abus to work on a real Apple II bus.
    Set up text memory shadowing and fixed a few abus issues:
    * Keep input synchronizer enabled on the PHI0 clock because it
    messes up the PIO in weird ways.
    * Sample DEVSEL at an appropriate time within phase 0
    Text memory shadowing works now, as well as device read cycle handling
    [abus.c]
2021-12-29 Remove unused PWM library
2022-01-01 Complete memory shadowing
    Add shadowing of text and hires memory plus the graphics mode soft-switches
2022-01-02 Add the schematics
    [AppleVGA.kicad_pcb, AppleVGA.sch, AppleVGA_Connections.sch]
2022-01-02 hires mode prototype
2022-01-20 Don't latch in the PAGE2 value for an entire frame
    Check the PAGE2 soft-switch more frequently so that the 'inactive'
    page's content won't be rendered sooner after a page flip happens.
    This resolves the flickering in Choplifter
2022-01-25 Add some images from the prototype
2022-08-30 Migration to KiCAD 6.0; obsolete KiCAD project files removed
    [AppleVGA.kicad_pcb, AppleVGA.kicad_sch, AppleVGA.sch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]
2022-08-31 Bill Of Materials CSV added
    [AppleVGA.kicad_pcb, AppleVGA_BOM.csv]
2022-09-08 Minor cleanups after KiCad6 conversion
    * Fixed the 3.3v net symbol that changed in KiCad6
    * Updated the Pico symbol & footprint to the latest version
    [AppleVGA.kicad_pcb, AppleVGA.kicad_sch, AppleVGA_Connections.kicad_sch]
2022-09-08 Error fix: Input Power pin not driven by Output Powers pins
    [AppleVGA.kicad_sch, AppleVGA_Connections.kicad_sch]
2022-09-26 Pico README added
2023-06-20 Update pico_sdk_import.cmake from current pico-sdk
2023-06-21 Add tentative clang-format configuration
    Initial clang-format configuration that is as close to the
    current formatting as I think it can be.
2023-06-22 Updated format and fixed apple ii+ bug
    [abus.c, main.c]
2023-06-22 Fixed Initialization of VIDEO7 mode
    [abus.c]
2023-06-22 fixed white spaces and missing lores_dot_patterns.h files
    [abus.c]
2023-06-23 Fix VIDEO7 detection algo
    [abus.c]
2023-07-01 Adjust read_cycle timings in abus.pio
    Tried to get abus_device_read working again but the CPU is now
    just a bit too slow in putting the value into the FIFO.
    Updated all the timing estimates and confirmed with my scope
    that they're pretty close.
    [abus.c]
2023-07-01 II+ text font fixes
    Justify the characters at the bottom of the text cell to be true
    to the original. The IIe justifies them at the top so the lower-case
    characters can dip down lower.
    Also fix the '3' and '"' characters.
2023-07-02 Update RAM shadowing naming
    Small update to RAM shadowing to match the names used
    in the Apple IIe techical documentation, and added a
    reference to the memory soft-switches.
2023-07-02 Refactor soft-switch dispatching
    Using a table of functions so the execution time is O(1) for all soft-switch
    accesses. This squashes an 800ns processing time outlier when idling at the
    Basic prompt back down into the 200-300ns range.
2023-07-03 Fix a bug in double-hires mode selection
    Fix a bug where an incorrect video7 mode could be selected.
    I updated the 80COL/AN3 softswitch logic to more closely follow
    what's described in patent US4631692.
    The MODETEST test for double-hires now passes more reliably and
    King's Quest didn't break :D
    [abus.c]
2023-07-03 Fix aux memory write inconsistencies
    Fix the detection of writes to AUX memory so that it's consistent
    with a real IIe when various combinations of soft-switches are set.
    The BANKTEST results now match the real machine.
    [abus.c]
2023-07-04 Remove IOUDIS shadowing
    The value wasn't used anywhere and I confirmed on a real IIe that it doesn't
    seem to affect setting AN3 like some notes on the internet suggested.
    [abus.c]
2023-07-04 Replace a bunch of binary enums with bool types
    [abus.c]
2023-07-09 Increase double-hires mode switch accuracy
    Update the double-hires mode soft-soft check to be more accurate to
    what I measured on my read IIe. Double-hires only seems to get enabled
    when both 80COL and DHIRES are set.
2023-07-20 Add scanline emulation
    Finish the scanline emulation for lores modes and add a soft switch
    so it can be enabled on the fly with a POKE.
    I also shuffled around the code in 'abus_loop' a bit to try and
    get read_cycle working more reliably (before resorting to assembly),
    with some success!
2023-07-24 Add back the F/B hires mode
    Add back the foreground/background hires mode now that I understand
    how it gets enabled (and how I broke it before :O). It's not a double-hires
    mode but the SDK enables the double-hires soft switch.
2023-07-24 Optimize dhires mixed mono/color mode to fix some jitter
2023-07-25 Fix rendering artifacts in video-7 mixed mode (pt.1)
    Rewrote most of the mixed video-7 rendering code to properly handle
    when the 'mode' changes in bytes that don't align with the 4-bit dhires
    pixel color codes.
    It resolves the artifacts I see in the AppleColor demo disk progams,
    but is currently too slow to render the entire screen in time.
2023-07-28 Make current monochrome modes consistent
    Make the currently implemented monochrome modes consistently get enabled when
    the soft_monochrom soft-switch is set and also make the use of the monochrome
    mode colors consistent across the current renderers.
2023-07-29 Add a couple RGB constants for future testing
2023-07-30 Rename a couple variables to improve readability
2023-09-09 Fix CPU reset detection
    This fixes the card inadvertently resetting and switching
    to text mode between levels in Stellar 7.
    I think this happens because Stellar 7 uses the ROMs as randomness for the
    warp sounds and if it happened to read the reset vector address then it would
    have triggered this bug.
    Thanks to @dhgoss for reporting!
    [abus.c]
2023-09-09 Remove read_cycle support
    I'm removing support for the firmware to be able to put data on the data
    bus in response to a device read cycle. The GPIO currently connected to
    the Data transceiver direction will be hard-coded as an input pulled low
    to preserve compatibility with the current (rev A) schematic.
    I originally intended to use this to add Videx card emulation but have
    abandoned that idea because:
    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
2023-09-17 Check in rev B KiCad 7 project
    [AppleVGA-B_Cu.gbr, AppleVGA-B_Mask.gbr, AppleVGA-Edge_Cuts.gbr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]
2023-09-17 Check in the KiCad project for the connector board
    [AppleVGA-Connector-B_Cu.gbr, AppleVGA-Connector-B_Mask.gbr, AppleVGA-Connector-Edge_Cuts.gbr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]
2023-09-30 Add an assembly guide
2023-09-30 Add a note about the hex standoffs
2023-11-30 Allow character generator modifications
    Add a couple registers to allow text character patterns to be
    changed on the fly.
2023-12-10 Improve reset detection
    Mimic the algorithm that the Apple IIe IOU chips uses to detect
    CPU resets from bus activity to reduce the possibility of false
    positives even more.
    [abus.c]
2024-01-13 Move the VGA card's custom register logic into device_regs.c
2024-01-13 Add basic config restoration on power-up
    Add the infrastructure for config saving & restoration and
    ensure that the configuration is read on power-up, falling back
    to default values if no configuration has ever been saved.
2024-01-13 Add register 0x04 for device commands
2024-01-13 Add command for (re)loading a character ROM
    Start adding support for switching between standard character ROMs by
    adding a command to load 1 of 16 in-built ROMs.
    Now instead of having a separate built variant for II+ lower-case text,
    both the normal and lower-case fonts are built-in and can be switched
    with a register setting.
2024-03-08 . adding support to videx card on slot 3 . adding videx text fonts
2024-03-08 Update videx soft video switch
    Update the Videx 80-column mode switch check so that 80 column mode
    is only displayed when the "color killer is on", i.e. only if the II+
    video mode is text mode. This matches how the real VideoTerm video
    switch works.
2024-03-08 Small Videx rendering fix
    Calculate the text window's start address and cursor
    address one at the start of the rendering frame to limit
    scrolling artifacts.
2024-03-15 Convert the AppleVGA KiCad project to KiCad 8
    [AppleVGA.kicad_pcb, AppleVGA.kicad_sch]
2024-03-15 Convert the AppleVGA-Connector KiCad project to KiCad 8
    [AppleVGA-Connector.kicad_pcb, AppleVGA-Connector.kicad_sch]
2024-11-06 Fixes for pico-sdk 2.0.0 release

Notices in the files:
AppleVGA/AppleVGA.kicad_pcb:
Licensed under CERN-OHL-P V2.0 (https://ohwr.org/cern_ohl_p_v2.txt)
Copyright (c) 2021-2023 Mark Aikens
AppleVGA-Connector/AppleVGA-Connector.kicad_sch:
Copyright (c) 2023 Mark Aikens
